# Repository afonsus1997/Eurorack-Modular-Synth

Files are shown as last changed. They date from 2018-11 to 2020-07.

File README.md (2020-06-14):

# Eurorack Modular Synth

## VCO

14 HP Digital voltage controlled oscillator.

### Main features

- Inputs
  - CV 1V/octave
  - FM in
  - Gate in
  - PWM in

* Output
  * Dual configurable audio outputs

#### Other features

Display LEDs for each audio input/output for visual feedback and for menu selection with the encoder.

## Power Supply

Using power supply design by [SyntherJack](https://syntherjack.net/)

* More information on the [project page](https://syntherjack.net/modular-synth-power-supply/)

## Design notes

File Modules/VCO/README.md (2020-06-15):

# VCO

Full DDS VCO module 

#### Dimensions

* 14HP (128.5x70.8mm)
  * PCB size (110x69mm)

### Main features

* Inputs
  * CV 1V/octave
  * FM in
  * Sync in
  * PWM in
* Output
  * Dual audio output with selectable waveforms

#### Main components

* Microcontroller
  * STM32F103RCT6 
* ADC
  * MCP3204
    * 12bit
    * 100ksps/4 channels
* DAC
  * DAC8551
    * 200ksps
    * 16bit
    * 1 channel
  * PCM1781DBQR
    * 192khz
    * 24bit
    * 2channel

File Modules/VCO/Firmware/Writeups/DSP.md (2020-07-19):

## Digital Representation

DAC output is 24bit -> 32bit variables are going to be used

int32: -4294967296 to +4294967295

## Ramp Integrator

-4294967296 to +4294967295

Ti/Ts = (2^32)/delta_i

fi = ((delta_i)/(2^32))*fs

delta_i = ((2^32)*fi)/fs

for addressing the wave table:

if wavetable only has half of the wave:

bit0 = sign

bit1:bit(number of wavetable samples+1) = wavetable addressing

bit(number of wavetable samples+2):bit31 = discarded

## CV Volt/Octave

The most popular choice seems to be that 0V is C2 (embraced by Doepfer and Kenton)

```
frequency = 440 / 2 ** 2.75 * 2 ** voltage
```

```
for pitch in range(61):
	voltage = pitch / 12
	frequency = 440 / 2 ** 2.75 * 2 ** voltage
	print(frequency)
```

http://bytenoise.co.uk/CV-gate

## Input sampling

input voltages 0 - 4.096

1st: 4096*0.001 (Q0 * Q15 = Q15) (Qm*Qk = Qm+k+1-n)

	-> 4096 * 32.768 = 134217.728

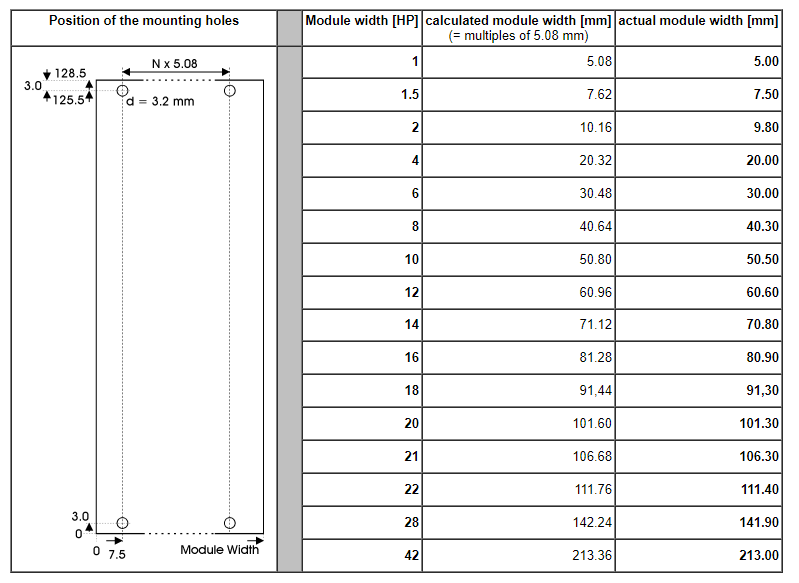
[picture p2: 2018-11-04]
Refs/Plate Sizes.png

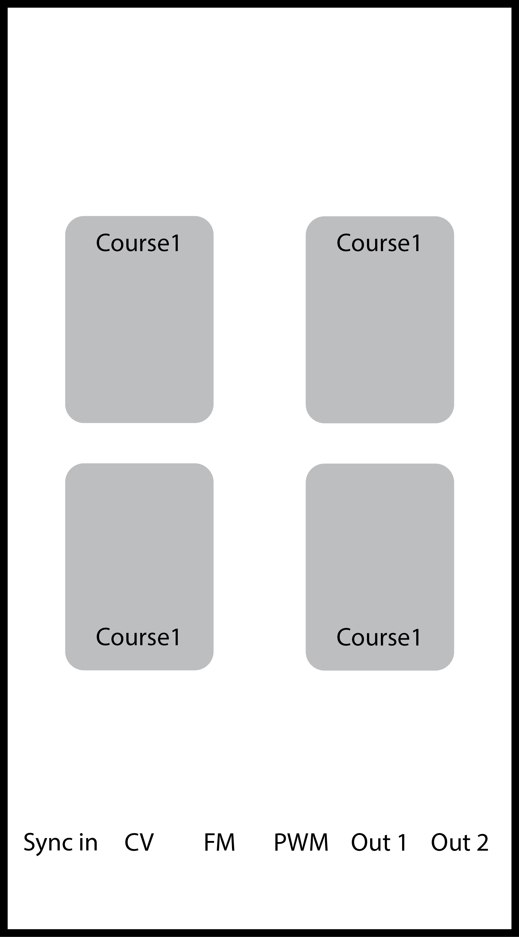
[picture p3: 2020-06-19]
Modules/VCO/Plate/VCO.png

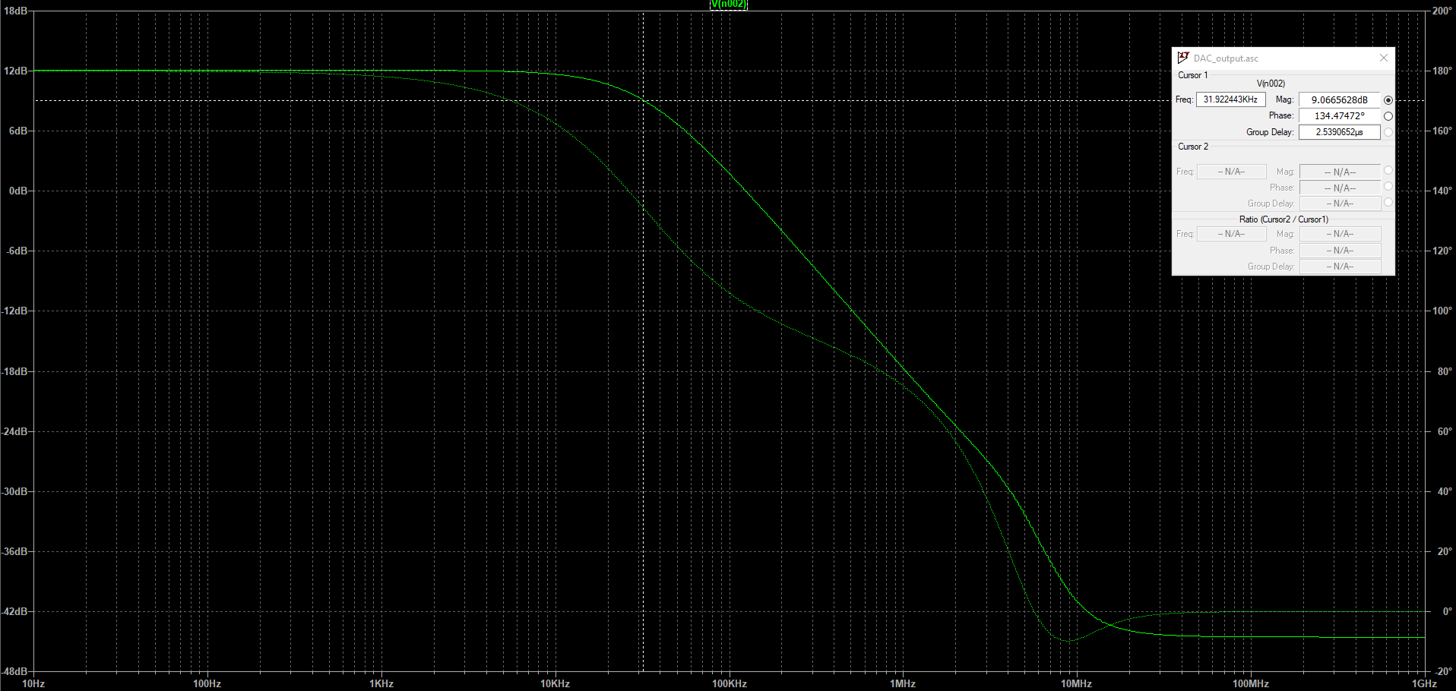
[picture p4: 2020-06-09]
Modules/VCO/Simulations/zero_impedance_output.png

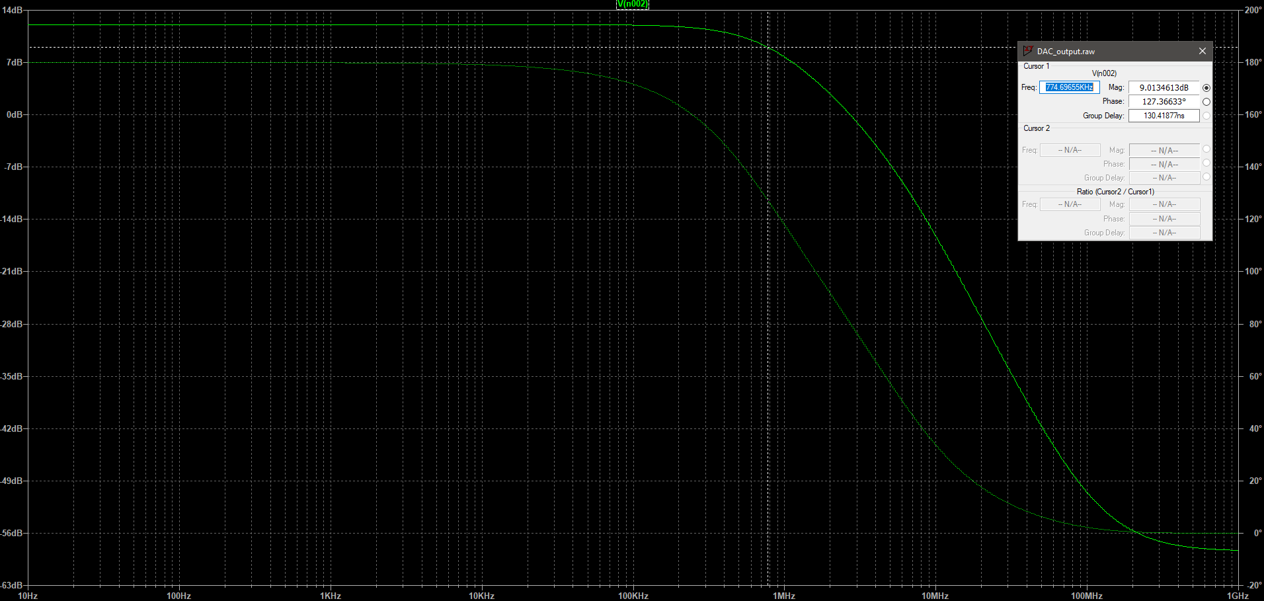
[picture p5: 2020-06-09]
Modules/VCO/Simulations/normal_feedback.png

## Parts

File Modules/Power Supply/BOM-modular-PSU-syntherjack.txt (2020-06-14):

Partlist for Euro Modular Synthesizer PSU

Qty Value     		        Parts                                                                                                             

Capacitors
                                                                                                          
4   1000u/25V       		C1, C2, C3, C4 
2   100n       				C5, C6 
2   10u/25V      			C7, C8 
2   1u/25V (tantalium)   	C9, C10                                                                                                           
                                                                                                              
Resistors 

4   2K 1%            		R1, R3, R8, R9     
2   240R 1%       			R2, R4                                                                                                           
2   100R          			R5, R6
1   14D391          		R7    

Semiconductors

2   1N4007          		D1, D2                                                                                                   
1   KBL06           		B1                                                                                                                
1   LM317T          		IC1                                                                                                               
1   LM337T          		IC2  
2   3mm LED        			LED1, LED2 

Other

13  6,3mm connector  +V-OUT1, +V-OUT2, +V-OUT3, -V-OUT1, -V-OUT2, -V-OUT3, AC-IN1, AC-IN2, AC-IN3, AC-IN4, GND-OUT1, GND-OUT2, GND-OUT3
2	Heatsink 6400B-P3 AAVID THERMALLOY (or similar that fits)
1	Toroidal transformer 60VA, 2x14V
1	100x160mm one-sided PCB

Notes:

Use C1/C2/C3/C4 1000u/25V or C1/C3 2200u/25V.

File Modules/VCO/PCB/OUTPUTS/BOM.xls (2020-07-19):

Designator | Value | Stock | Comment | Description | Quantity | Footprint | LibRef
RM14 | SHORT |  | Res1 | Resistor | 1 | RES0603R | Res1
RM13 | OPEN |  | Res1 | Resistor | 1 | RES0603R | Res1
CM1 | 100u |  | 100u |  | 1 | C 0603 / 1608 | Capacitor
CP1, CP2 | 100pF |  | Cap Pol2 | Polarized Capacitor (Axial) | 2 | C-RAD-4.5 | Cap Pol2
CP4, CP6 | 100n |  | Cap | Capacitor | 2 | C 0603 / 1608 | Cap
RD12, RD22, RD32, RD42, RD52, RD62, RIS11, RIS21, RIS31, RIS36, RIS41, ROS16, ROS26 | 100k |  | Res1, [NoValue] | Resistor | 13 | RES0603R | Res1
RD13, RD23, RD33, RD43, RD53, RD63 | 49.9k |  | Res1 | Resistor | 6 | RES0603R | Res1
COS14, COS24 | 47p |  | 47p |  | 2 | C 0603 / 1608 | Capacitor
RIS12, RIS22, RIS32 | 41.2k |  | Res1 | Resistor | 3 | RES0603R | Res1
ROS14, ROS24 | 30k |  |  | Resistor | 2 | RES0603R | Res1
RIS13, RIS14, RIS23, RIS24, RIS33, RIS34 | 24.9k |  | Res1 | Resistor | 6 | RES0603R | Res1
CP3, CP5 | 22u |  | Cap Pol2 | Polarized Capacitor (Axial) | 2 | C 0603 / 1608 | Cap Pol2
RIS35, ROS15, ROS25 | 20k |  |  | Potentiometer | 3 | SMD_POT_3x3mm | RPot
RM3, RM4, RM5, RM6 | 20k |  |  | Potentiometer | 4 | POT-rv09 | RPot
CM2, CM3 | 18p |  | 18pF |  | 2 | C 0603 / 1608 | Capacitor
CDAC3, CDAC5 | 10uF |  | Cap Pol1 | Polarized Capacitor (Radial) | 2 | C-RAD-4.5 | Cap Pol1
CADC2 | 10u |  | 10u |  | 1 | C 0603 / 1608 | Capacitor
COS13, COS23 | 10u |  | Cap Pol1 | Polarized Capacitor (Radial) | 2 | C-RAD-4.5 | Cap Pol1
CM5 | 10n |  | 10n |  | 1 | C 0603 / 1608 | Capacitor
LP1, LP2 | 10mH |  | Ferrite | Ferrite, Inductor | 2 | RES0805R | Inductor
RD11, RD21, RD31, RD41, RD51, RD61 | 10k |  | Res1 | Resistor | 6 | RES0603R | Res1
ROS11, ROS13, ROS21, ROS23 | 5.6k |  |  | Resistor | 4 | RES0603R | Res1
CDAC1, CDAC2 | 4.7-10uF |  | Cap Pol1 | Polarized Capacitor (Radial) | 2 | C-RAD-4.5 | Cap Pol1
COS11, COS21 | 3.9n |  | 3.9n |  | 2 | C 0603 / 1608 | Capacitor
ROS12, ROS22 | 3k |  |  | Resistor | 2 | RES0603R | Res1
RIS43 | 2k |  | Res1 | Resistor | 1 | RES0603R | Res1
CADC1, CADC4, CM4 | 1u |  | 1u |  | 3 | C 0603 / 1608 | Capacitor
CIS11, CIS21, CIS31, COS12, COS22 | 1n |  | Cap, 1n | Capacitor, [NoValue] | 5 | C 0603 / 1608 | Cap, Capacitor
RIS42, RM1, RM2, RM7, RM8, RM9, RM10, RM11, RM12, ROS17, ROS27 | 1k |  | Res1, [NoValue] | Resistor | 11 | RES0603R | Res1
CADC3, CD11, CD21, CD31, CD41, CD51, CD61, CDAC4, CIS32, CIS33, CIS34, CIS35, COS15, COS16, COS25, COS26 | 0.1u |  | 0.1u, Cap | [NoValue], Capacitor | 16 | C 0603 / 1608 | Capacitor, Cap
NT1, NT2 | 0 |  | Net_Tie | Resistor | 2 | RES0603R | Res1
RDAC1:4 |  |  | 742C083121JP | Res Thick Film Array 120 Ohm 5% 1/4W Â±200ppm/Â°C ISOL Molded 8-Pin 1206_4 X 0603_ Concave SMD Paper T/R | 1 | RESARRAY(4x0603) | Resistor Array 4x
UADC1 |  |  | MCP3204-CI/SL | 12 Bit Analog to Digital Converter 2, 4 Input 1 SAR 14-SOIC | 1 | SOIC-14 | MCP3204-CI/SL
UDAC1 |  |  | PCM1781DBQR | Converters - Digital to Analog _DAC_ 24-Bit, 192kHz, Ster Delta-Sig Audio DAC | 1 | SOP16-63P600X175-16N | PCM1781DBQR
UM1 |  |  | STM32F103RCT6 | ARMÂ® CortexÂ®-M3 STM32F1 Microcontroller IC 32-Bit 72MHz 256KB _256K x 8_ FLASH | 1 | QFP64P1200X1200X160-64N | STM32F103RCT6
XM1 |  |  | TSX-3225 | 16MHz Â±10ppm Crystal 9pF 60 Ohms 4-SMD, No Lead | 1 | TSX-3225 | TSX-3225
DM1, DM2, DM3, DM4, DM5, DM6 |  |  | LED0 | Typical INFRARED GaAs LED | 6 | LED2-2.54-D5.0MM | LED0
DP1, DP2 |  |  | 1N5819 |  | 2 | DO-41 | Diode
J02, JI1, JI2, JI3, JI4, JO1 |  |  | PJ-301 | https://www.snapeda.com/parts/PJ-301BM/Tayda%20Electronics/datasheet/ https://pt.aliexpress.com/item/32841677168.html?spm=a2g03.12057483.0.0.6dda4aeaXiyjRe https://lh3.googleusercontent.com/proxy/ZbPfZslDxdj8iWSgzh0kYZVEID9Zfc6SS9ZRHYvUB6heg4eTAyEEOQEiXlT2FamGh3ujXXQ57fTjbGyEKtdVl3hemL66LOj7ZA | 6 | PJ-301 | PJ-301
PM1, PP1 |  |  | Header 5X2 | Header, 5-Pin, Dual row | 2 | HDR2X5 | Header 5X2
PM2 |  |  | Header 4 | Header, 4-Pin | 1 | HDR1X4 | Header 4
SJM1, SJM2 |  |  | 2-Way Solder Jumper |  | 2 | SOLDERJUMPER_2WAY_OPEN_NOPASTE | SOLDERJUMPER_2WAY0603
SM1 |  |  | Switch |  | 1 | PUSH_SMD_3x4 | B3U-1000P
SM2 |  |  | ENCODER |  | 1 | Rotary Encoder | ENCODER
UADC2 |  |  | 4.096 VREF | 4.096 Voltage reference | 1 | SOT-23-3 | MCP1541
UIS1, UIS2 |  |  | TL074 |  | 2 | SOIC-14 | TL074
UOS1, UOS2 |  |  | Dual NE5532 opamp |  | 2 | SOIC-8 | NE5532
UP1, UP2 |  |  | 3v3 REG, 5VREG | LDO 3.3V/5V/12V | 2 | SOT-223-3 - REG | AMS1117

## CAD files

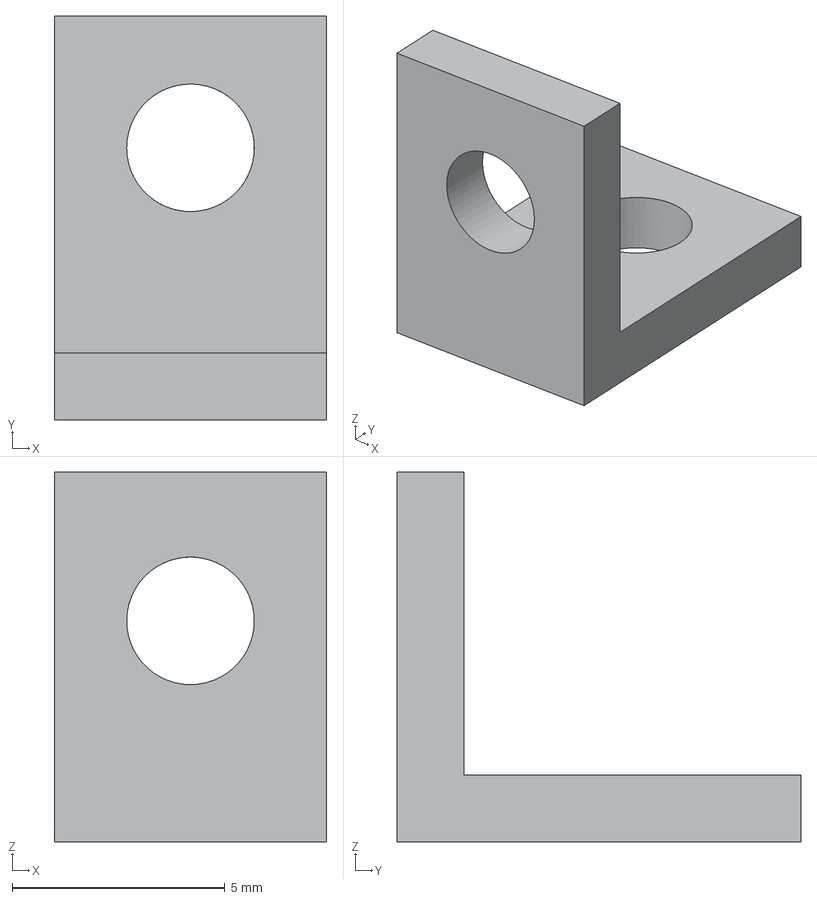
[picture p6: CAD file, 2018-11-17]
Modules/VCA/Altium 3D/L bracket.step
6.40 x 9.50 x 8.70 mm

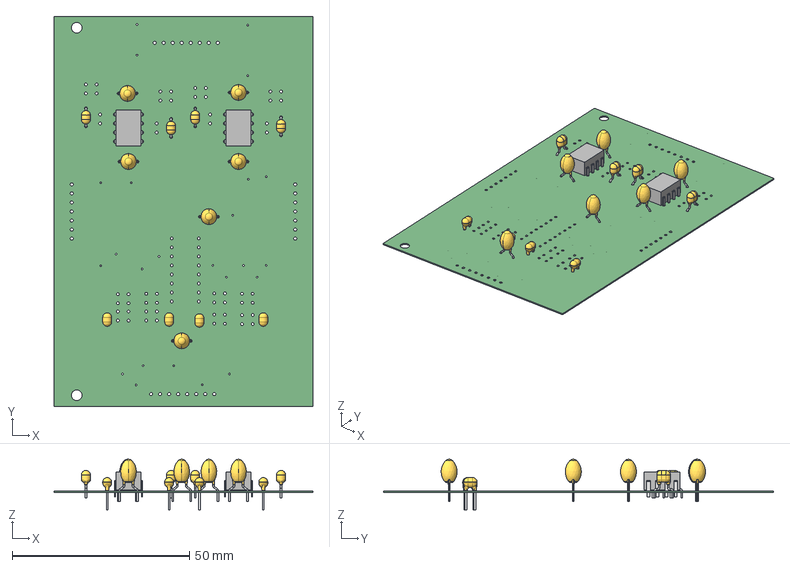
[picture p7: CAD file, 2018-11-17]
Modules/VCA/VCA_1/VCA_1.step
73.0 x 110.0 x 14.3 mm
Board
Extruded x 50
CAPPRB508-450X850 x 6
CAPRR254-254X381X381 x 4
CAPRR508-254X381X584 x 4

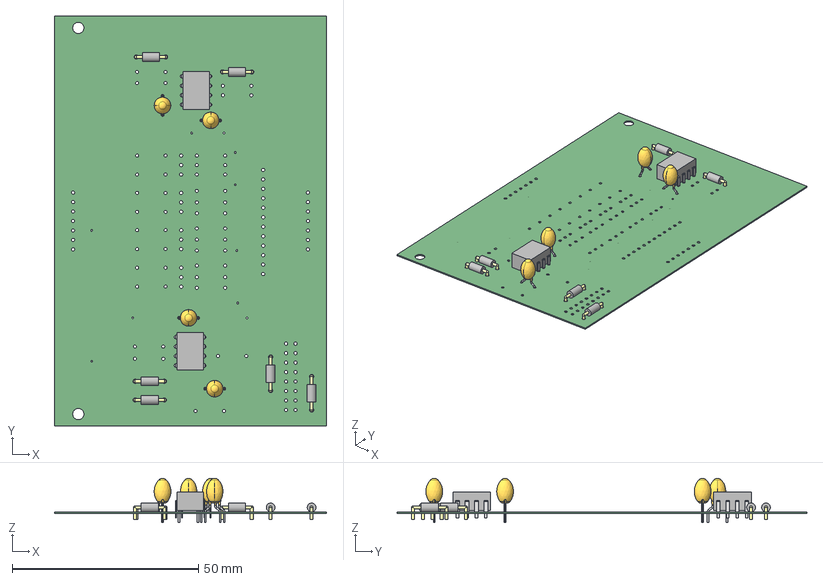
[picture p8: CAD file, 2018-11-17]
Modules/VCA/VCA_2/VCA_2.step
73.0 x 110.0 x 11.9 mm
Board
Extruded x 50
CAPPRB508-450X850 x 4

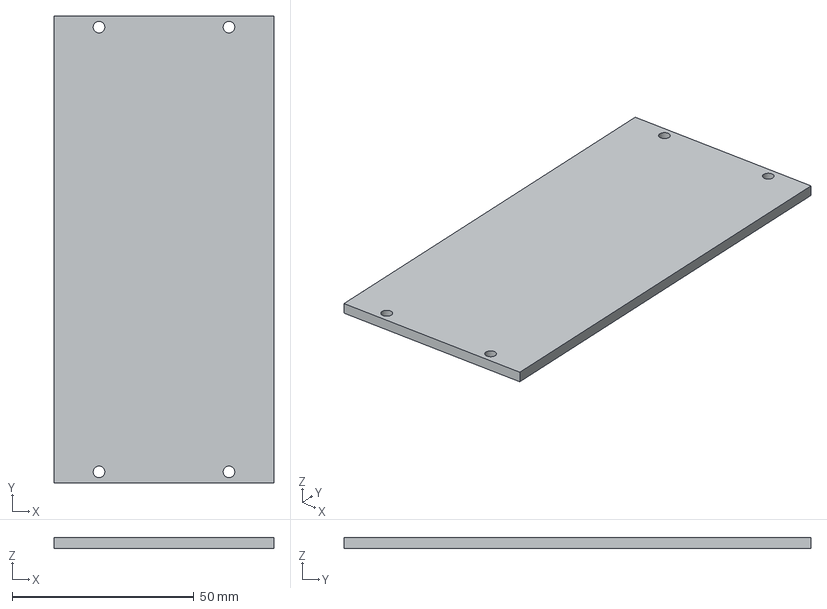
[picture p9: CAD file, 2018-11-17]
Modules/VCA/Altium 3D/VCA_face_plate.step
60.6 x 128.5 x 3.00 mm

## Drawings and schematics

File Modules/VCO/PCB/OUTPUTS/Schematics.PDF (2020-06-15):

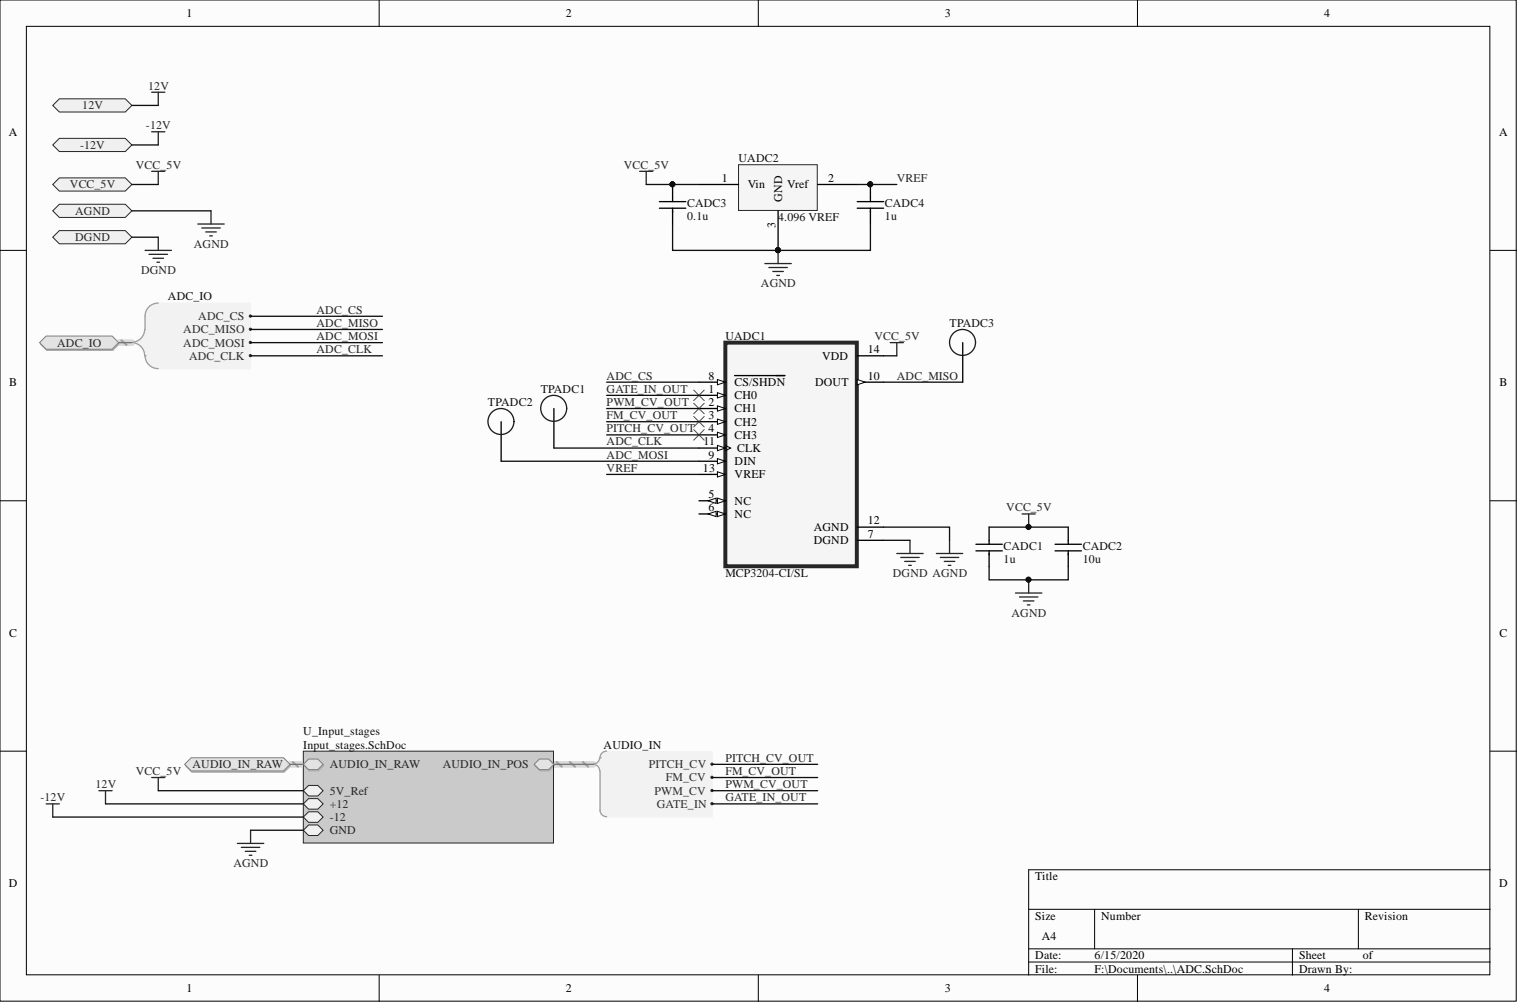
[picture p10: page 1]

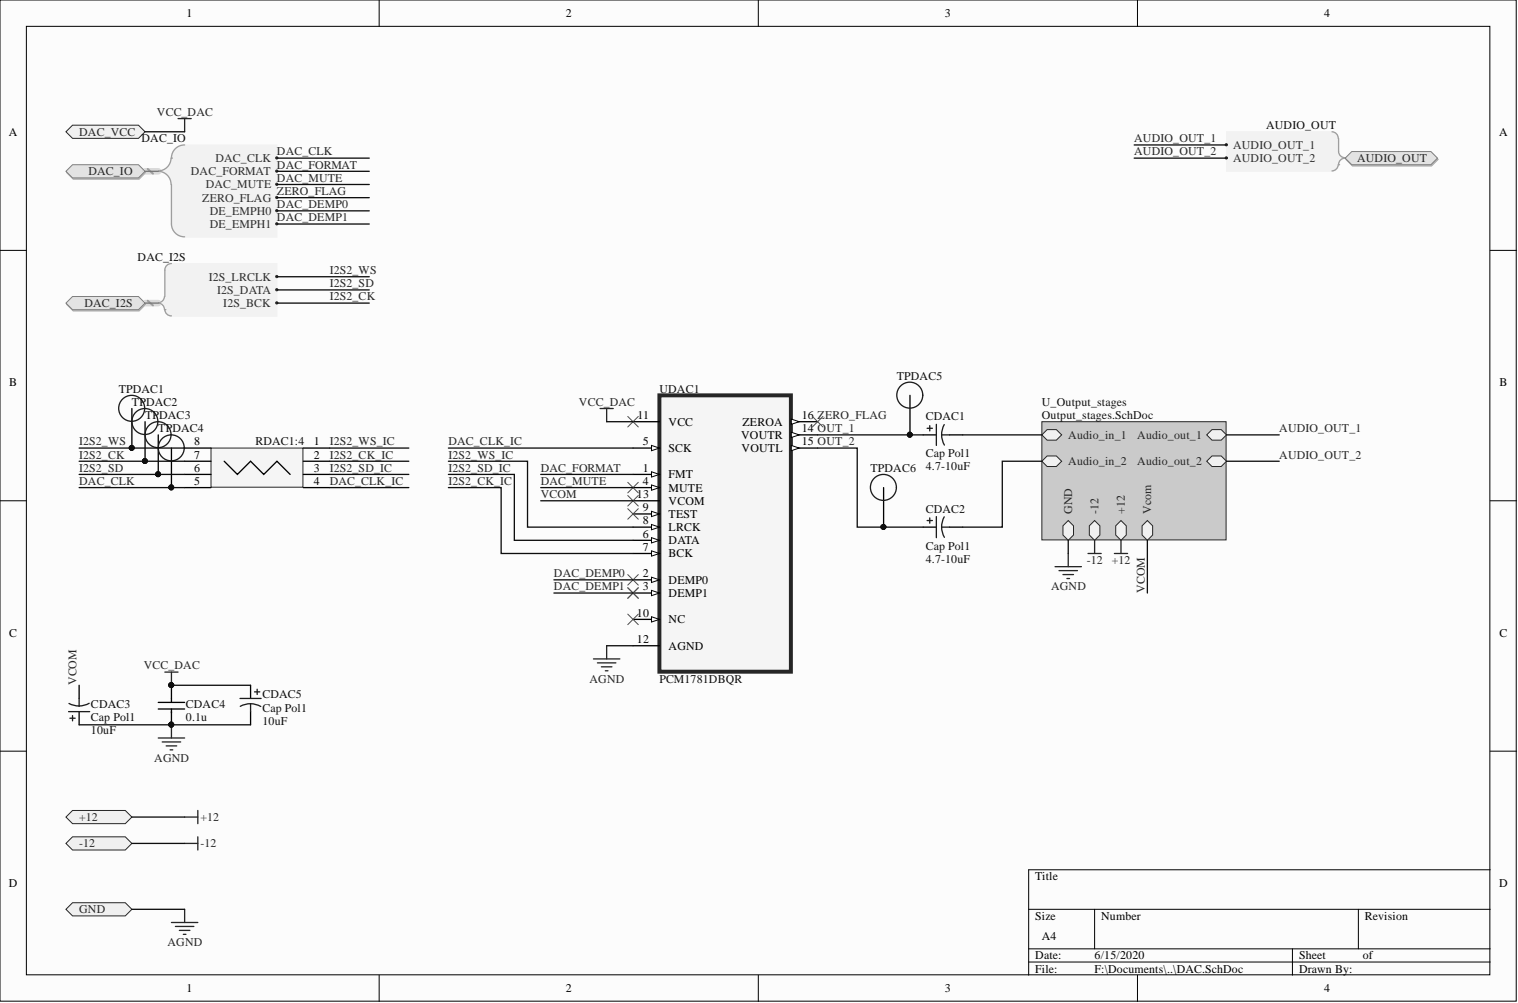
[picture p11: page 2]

MUTE 4

VCOM | VCOM 13 TEST 9

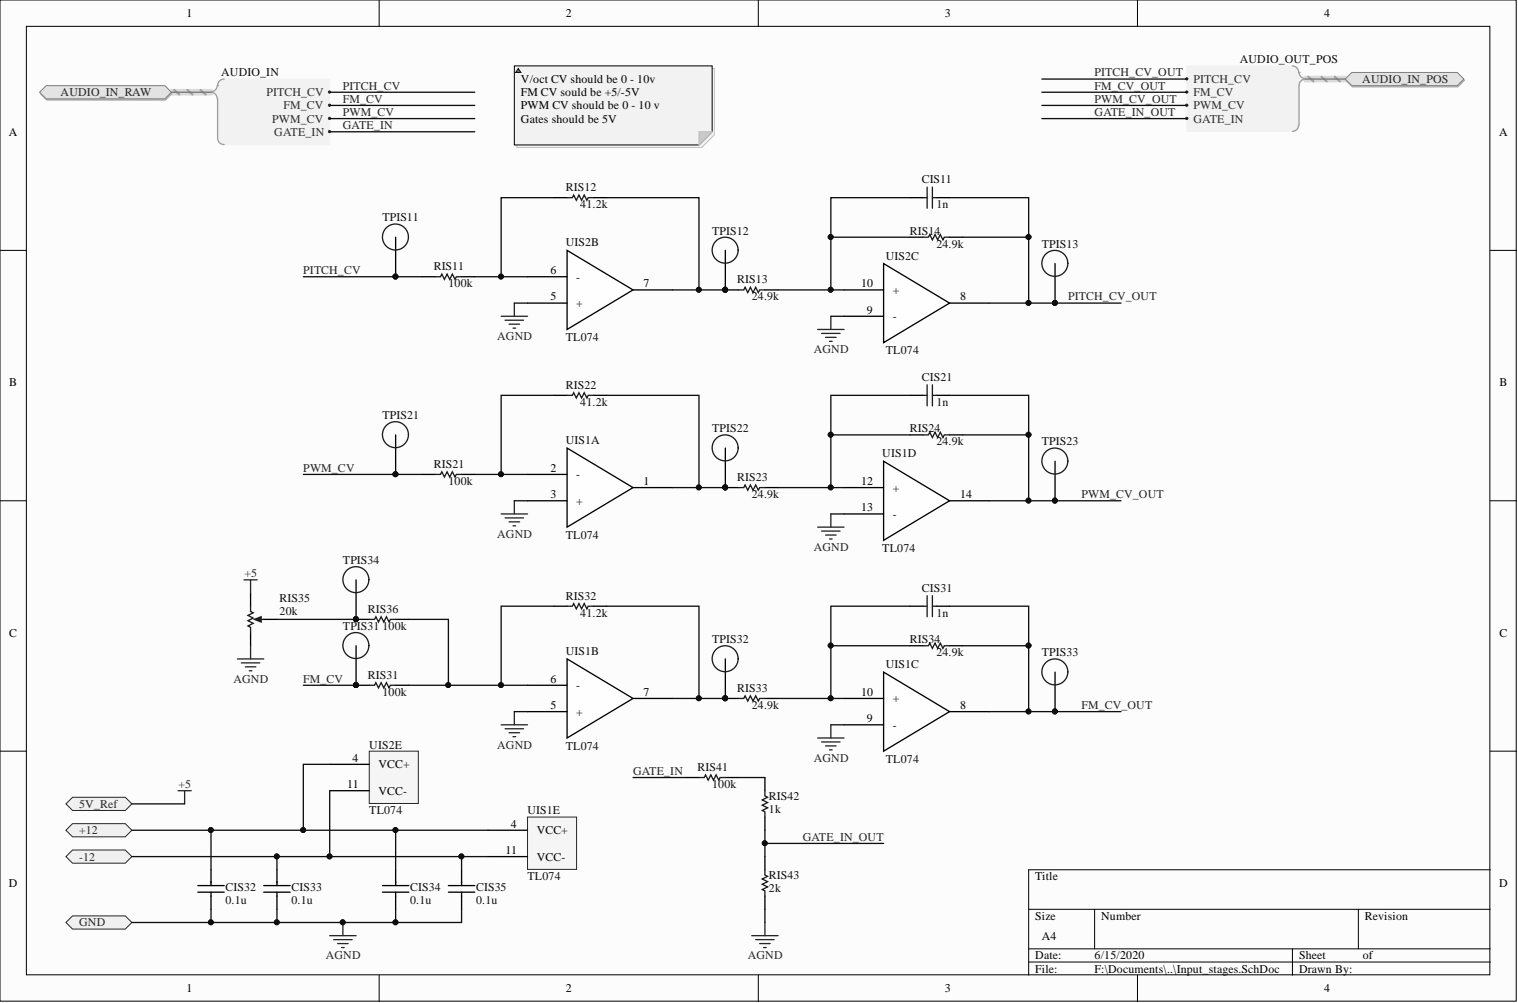
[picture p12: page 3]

V/oct CV should be 0 - 10v
FM CV sould be +5/-5V
PWM CV should be 0 - 10 v
Gates should be 5V

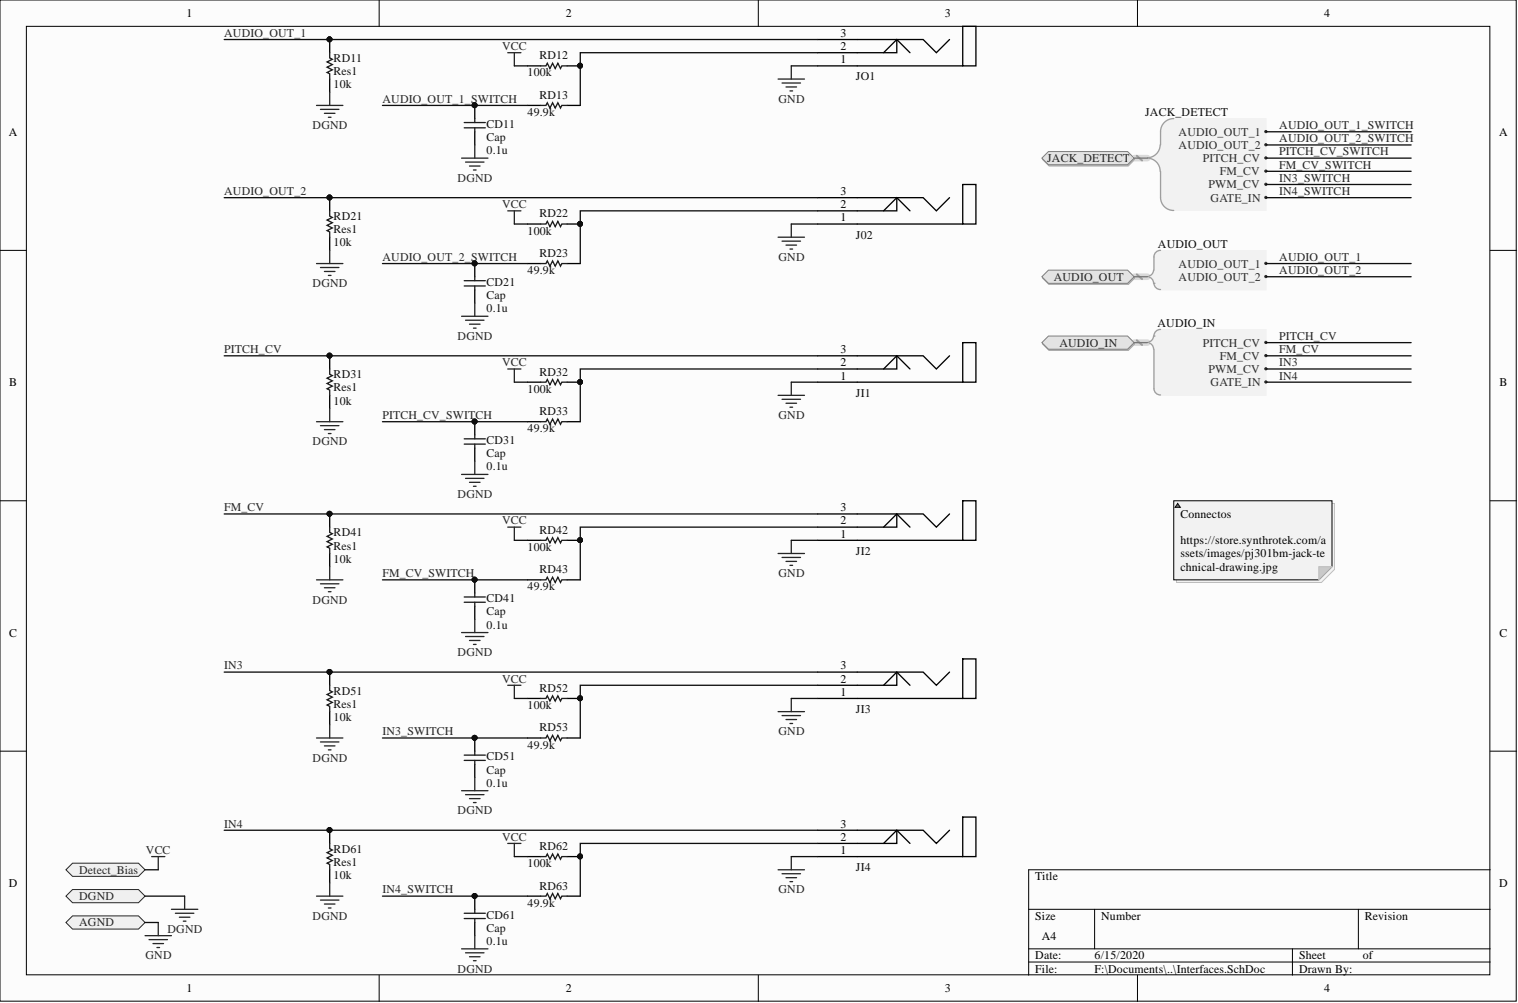
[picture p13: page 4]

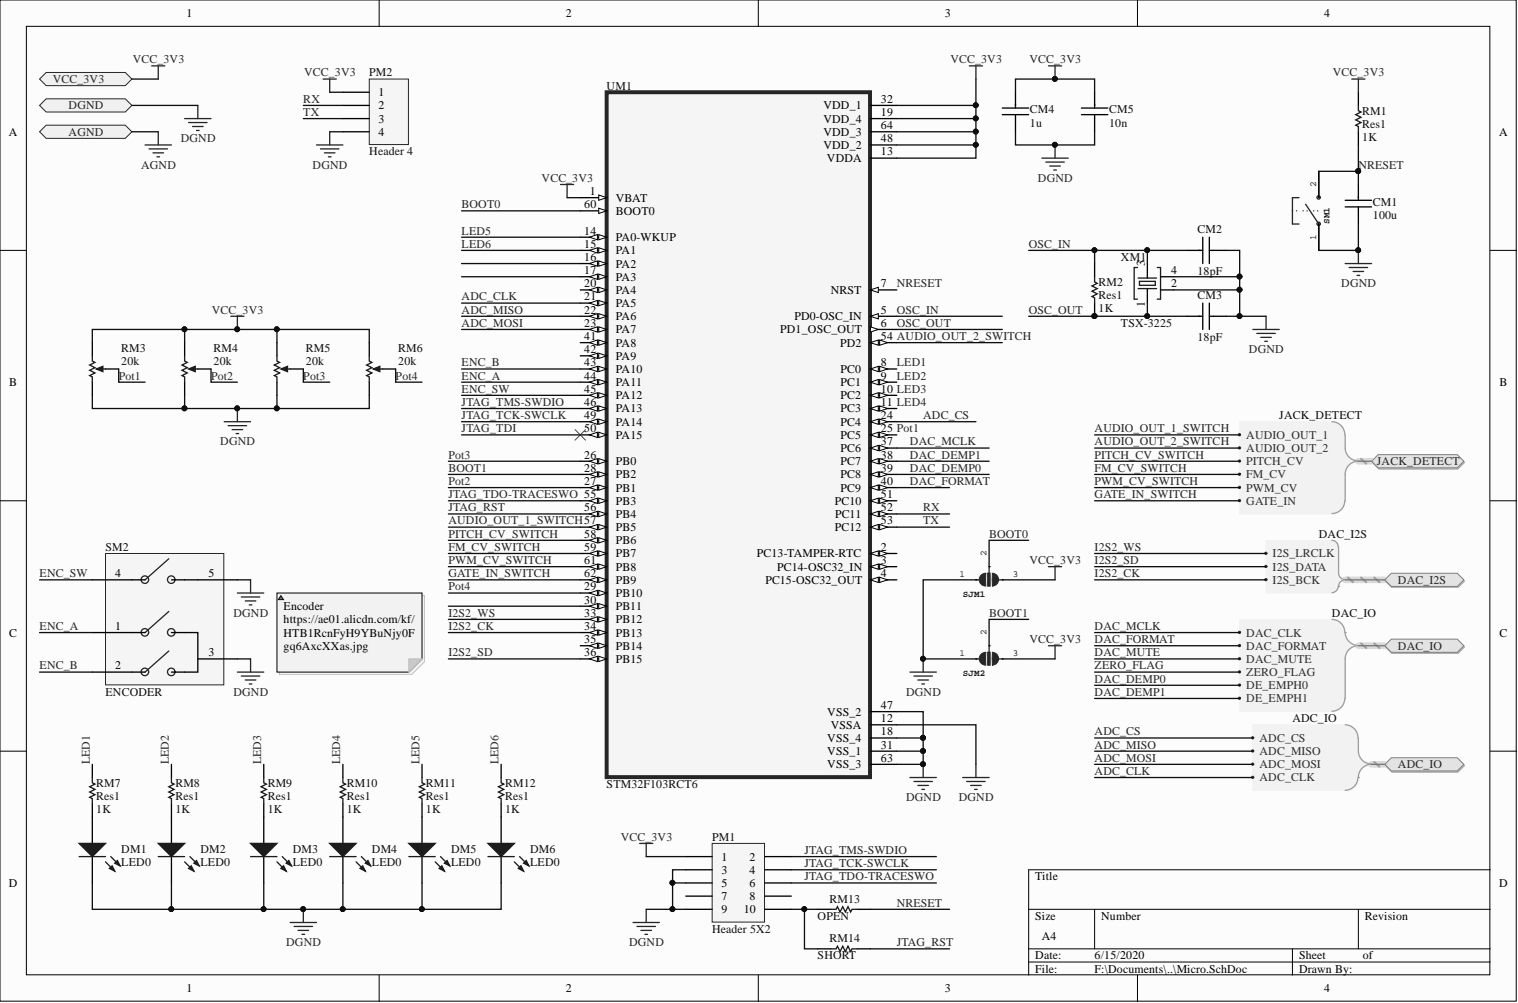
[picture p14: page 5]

1 2
1 8
3 1
6 3

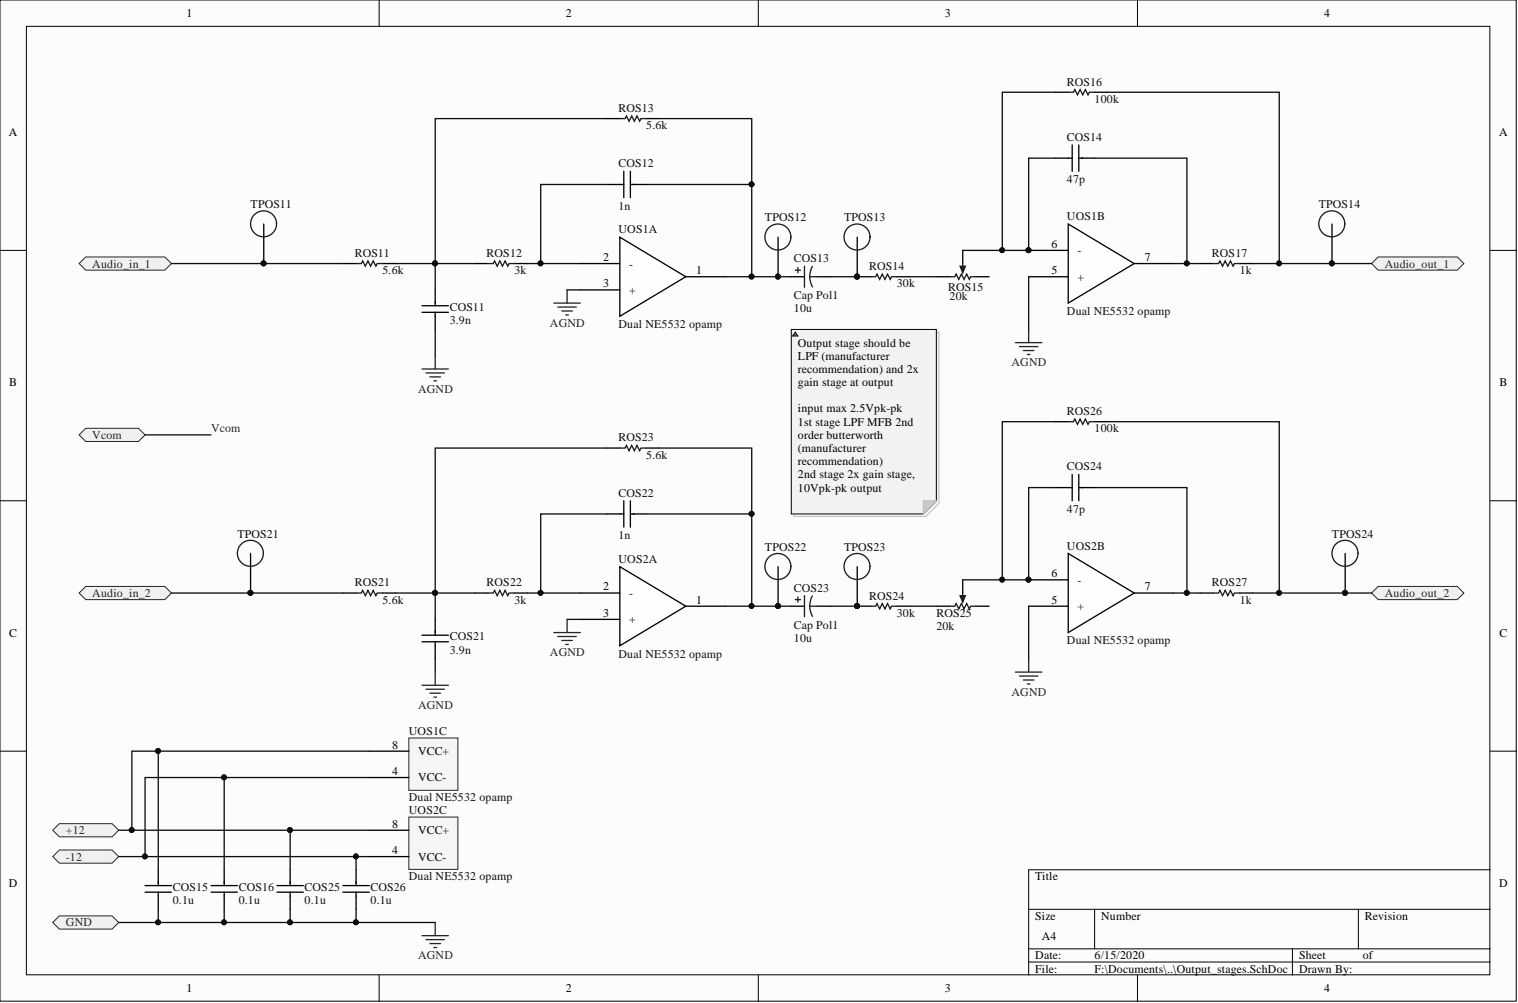
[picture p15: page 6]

Output stage should be
LPF (manufacturer
recommendation) and 2x
gain stage at output

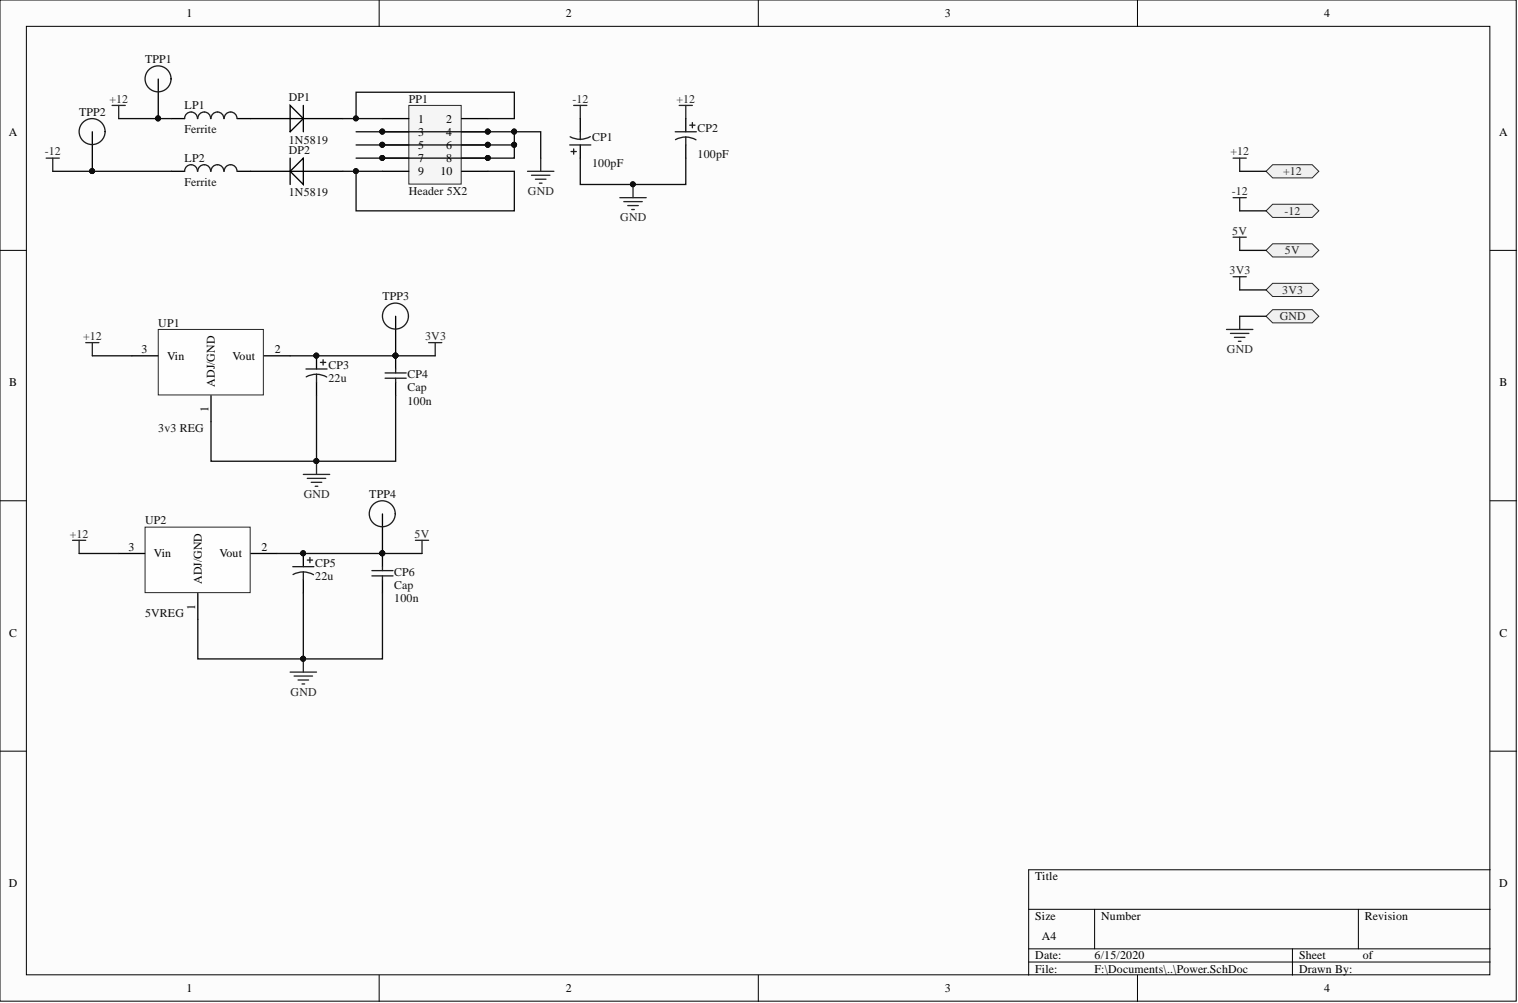
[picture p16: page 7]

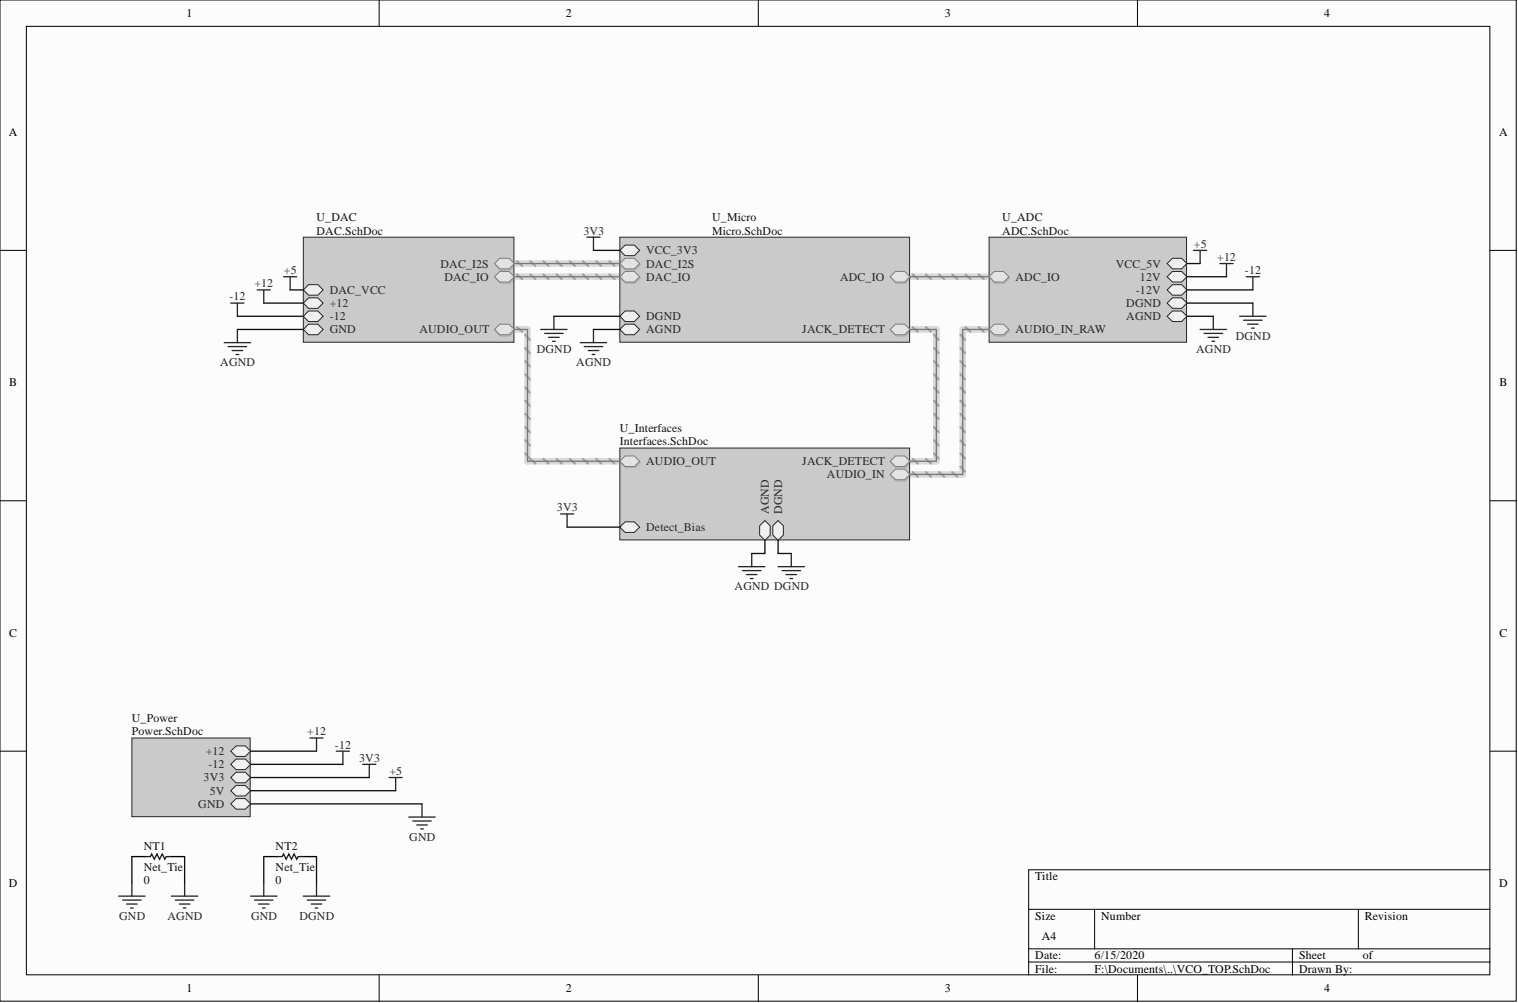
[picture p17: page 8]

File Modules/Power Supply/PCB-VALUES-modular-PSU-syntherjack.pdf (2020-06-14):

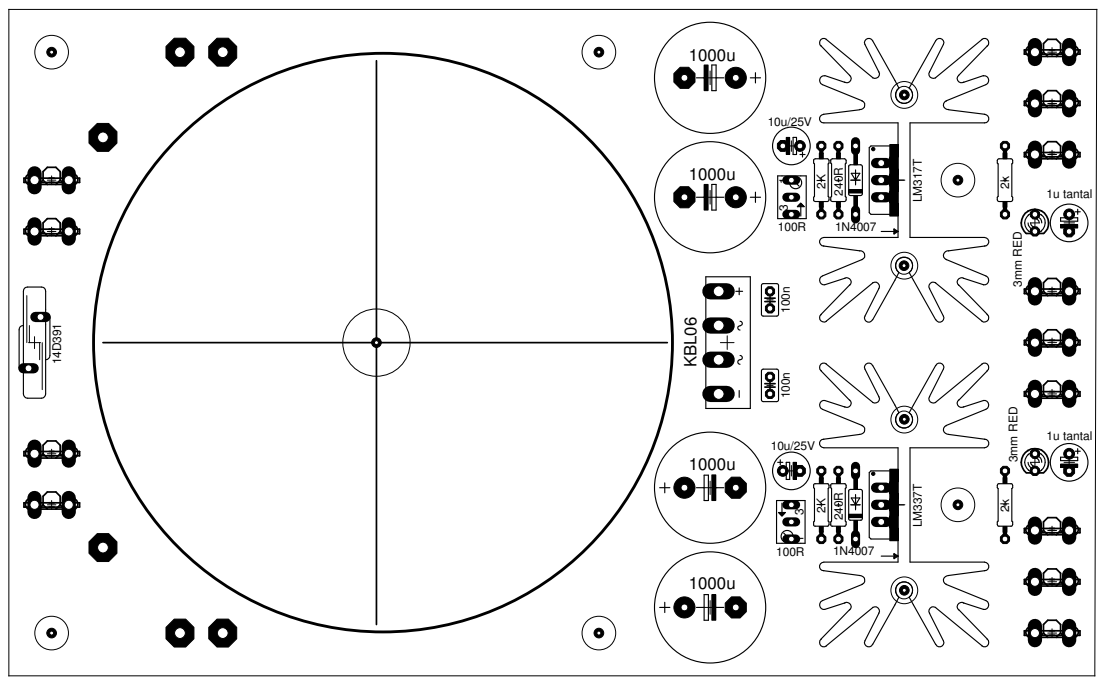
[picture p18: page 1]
KBL06; 1u tantal; 3mm RED 3mm RED 2k 2k

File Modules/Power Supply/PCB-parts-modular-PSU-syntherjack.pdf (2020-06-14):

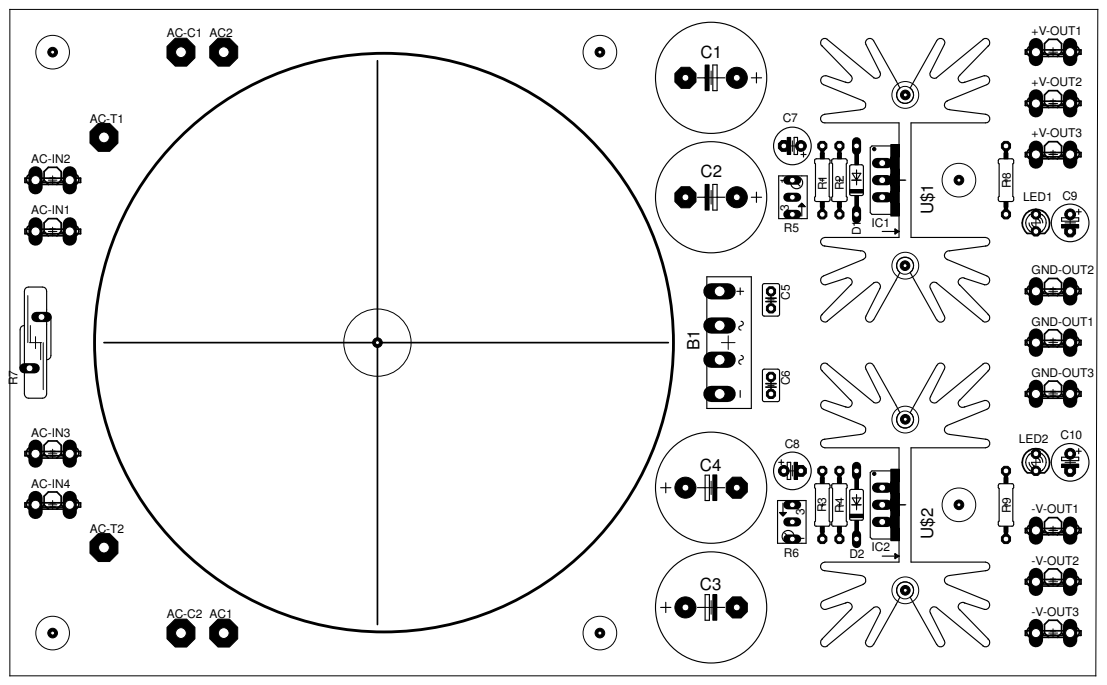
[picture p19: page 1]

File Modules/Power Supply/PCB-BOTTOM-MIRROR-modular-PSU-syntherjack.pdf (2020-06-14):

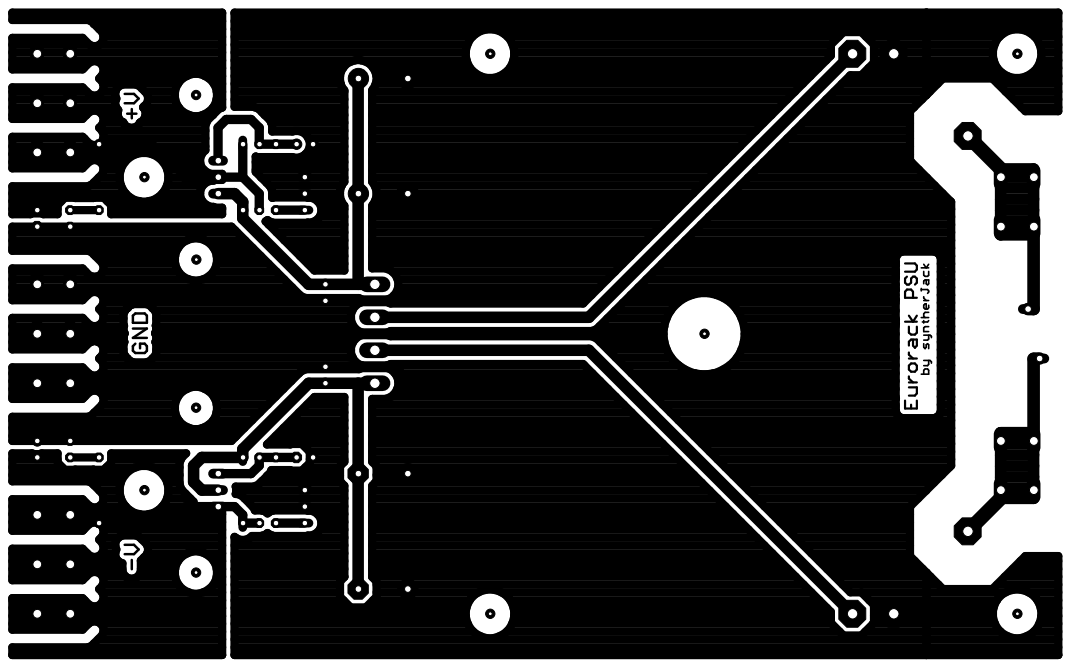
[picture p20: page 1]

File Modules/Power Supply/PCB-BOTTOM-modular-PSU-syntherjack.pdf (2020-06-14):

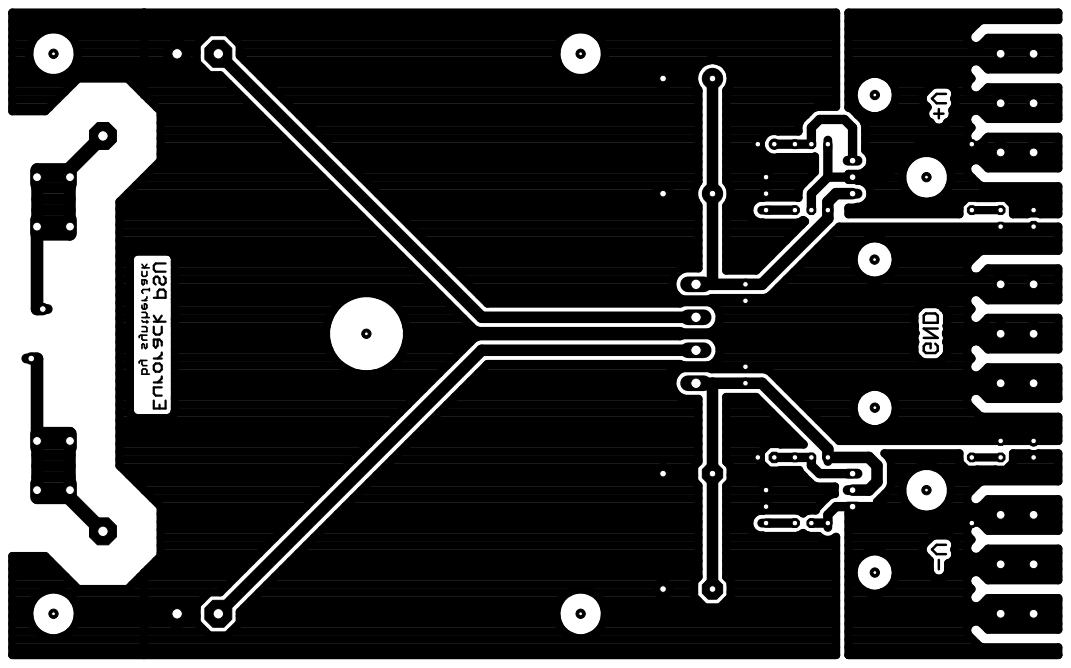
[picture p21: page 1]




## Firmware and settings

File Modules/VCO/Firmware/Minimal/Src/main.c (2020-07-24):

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

/* Includes ------------------------------------------------------------------*/
#include "main.h"

/* USER CODE BEGIN Includes */
#include "mcp3204.h"
#include "DSPmain.h"
#include "stm32_HAL.h"
#include "interfaces.h"
// extern uint32_t potVals[4];
/* USER CODE END Includes */

/* USER CODE BEGIN PTD */
uint16_t pot1, pot2, pot3, pot4;
uint16_t adcbuf[4];
// extern uint8_t jackStatus[6];
/* USER CODE END PTD */

ADC_HandleTypeDef hadc1;
DMA_HandleTypeDef hdma_adc1;

I2S_HandleTypeDef hi2s2;
DMA_HandleTypeDef hdma_spi2_tx;

SPI_HandleTypeDef hspi1;

TIM_HandleTypeDef htim6;

UART_HandleTypeDef huart4;

/* USER CODE BEGIN PV */
HAL_ADC_ConvCpltCallback(ADC_HandleTypeDef* hadc){
  for (int i = 0; i < 4; i++)
  {
    potVals[i] = adcbuf[i];
  }
  
}
/* USER CODE END PV */

void SystemClock_Config(void);
static void MX_GPIO_Init(void);
static void MX_DMA_Init(void);
static void MX_ADC1_Init(void);
static void MX_I2S2_Init(void);
static void MX_SPI1_Init(void);
static void MX_UART4_Init(void);
static void MX_TIM6_Init(void);
/**
  * @brief  The application entry point.
  * @retval int
  */
int main(void)
{
  /* USER CODE BEGIN 1 */
  // adcRead(1);
  /* USER CODE END 1 */
  

  /* MCU Configuration--------------------------------------------------------*/

  /* Reset of all peripherals, Initializes the Flash interface and the Systick. */
  HAL_Init();

  /* Configure the system clock */
  SystemClock_Config();

  /* Initialize all configured peripherals */
  MX_GPIO_Init();
  MX_DMA_Init();
  MX_ADC1_Init();
  MX_I2S2_Init();
  MX_SPI1_Init();
  MX_UART4_Init();
  MX_TIM6_Init();
  /* USER CODE BEGIN 2 */
  HAL_TIM_Base_Start_IT(&htim6);
  // HAL_ADCEx_Calibration_Start(&hadc1);
  HAL_ADC_Start_DMA(&hadc1, adcbuf, 4);
  // HAL_ADC_PollForConversion(&hadc1, HAL_MAX_DELAY);
  uint16_t raw;
  /* USER CODE END 2 */

  /* Infinite loop */
  /* USER CODE BEGIN WHILE */
  while (1)
  {
    /* USER CODE END WHILE */

    /* USER CODE BEGIN 3 */
    // pot1 = potVals[Pot1];
    // pot2 = potVals[Pot2];
    // pot3 = potVals[Pot3];
    // pot4 = potVals[Pot4];

    updateJackStatus();
    

  }
  /* USER CODE END 3 */
}

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


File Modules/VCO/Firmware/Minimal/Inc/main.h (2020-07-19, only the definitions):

#define LED1_Pin GPIO_PIN_0
#define LED1_GPIO_Port GPIOC
#define LED2_Pin GPIO_PIN_1
#define LED2_GPIO_Port GPIOC
#define LED3_Pin GPIO_PIN_2
#define LED3_GPIO_Port GPIOC
#define LED4_Pin GPIO_PIN_3
#define LED4_GPIO_Port GPIOC
#define LED5_Pin GPIO_PIN_0
#define LED5_GPIO_Port GPIOA
#define LED6_Pin GPIO_PIN_1
#define LED6_GPIO_Port GPIOA
#define POT4_Pin GPIO_PIN_4
#define POT4_GPIO_Port GPIOA
#define GPIO_ADC_CS_Pin GPIO_PIN_4
#define GPIO_ADC_CS_GPIO_Port GPIOC
#define POT1_Pin GPIO_PIN_5
#define POT1_GPIO_Port GPIOC
#define POT3_Pin GPIO_PIN_0
#define POT3_GPIO_Port GPIOB
#define POT2_Pin GPIO_PIN_1
#define POT2_GPIO_Port GPIOB
#define DEMP1_Pin GPIO_PIN_7
#define DEMP1_GPIO_Port GPIOC
#define DEMP0_Pin GPIO_PIN_8
#define DEMP0_GPIO_Port GPIOC
#define DACFORMAT_Pin GPIO_PIN_9
#define DACFORMAT_GPIO_Port GPIOC
#define ENCB_Pin GPIO_PIN_10
#define ENCB_GPIO_Port GPIOA
#define ENCA_Pin GPIO_PIN_11
#define ENCA_GPIO_Port GPIOA
#define ENCSW_Pin GPIO_PIN_12
#define ENCSW_GPIO_Port GPIOA
#define AUDIO_OUT_2_SW_Pin GPIO_PIN_2
#define AUDIO_OUT_2_SW_GPIO_Port GPIOD
#define AUDIO_OUT_1_SW_Pin GPIO_PIN_5
#define AUDIO_OUT_1_SW_GPIO_Port GPIOB
#define PITCH_CV_SWITCH_Pin GPIO_PIN_6
#define PITCH_CV_SWITCH_GPIO_Port GPIOB
#define FM_CV_SWITCH_Pin GPIO_PIN_7
#define FM_CV_SWITCH_GPIO_Port GPIOB
#define PWM_SW_Pin GPIO_PIN_8
#define PWM_SW_GPIO_Port GPIOB
#define GATE_SW_Pin GPIO_PIN_9
#define GATE_SW_GPIO_Port GPIOB

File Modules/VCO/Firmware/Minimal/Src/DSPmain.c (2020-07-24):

#include "DSPmain.h"


int32_t RampIntegratorState0 = 0;
int32_t RampIntegratorState1 = 0;

uint8_t currentWave0 = 0;
uint8_t currentWave1 = 0;

int16_t sampleBuffer1[SAMPLEBUFFERSIZE];
int16_t sampleBuffer2[SAMPLEBUFFERSIZE];

uint16_t transferBuffer1[TRANSFERBUFFERSIZE];
uint16_t transferBuffer2[TRANSFERBUFFERSIZE];



// void HAL_TIM_PeriodElapsedCallback(TIM_HandleTypeDef *htim)
// {
//     // if (htim->Instance == TIM6) {
        
//     // }
// }

extern "C" void HAL_I2S_TxCpltCallback(I2S_HandleTypeDef *hi2s)
{
  // second half finished, filling it up again while first  half is playing
  for (uint8_t i = 0; i < 25; i++)
  {
      
  }
  
}
extern "C" void HAL_I2S_TxHalfCpltCallback(I2S_HandleTypeDef *hi2s)
{
  // first half finished, filling it up again while second half is playing
}

int32_t NCO0(uint8_t wave, uint16_t freq){
    uint32_t delta_i;


    delta_i = (pow(2,32)*freq)/SAMPLING_FREQ;

    RampIntegratorState0 = RampIntegratorState0 + delta_i;

    switch (wave)
    {
    case sine:
        return sineProcessor(RampIntegratorState0);
        break;
    
    default:
        break;
    }

}

uint32_t sineProcessor(int16_t integratorState){
    int32_t preSine;
    uint32_t sineOut;
    preSine = RampIntegratorState0 >> SINE_SHIFT;
    preSine &= SINE_SHIFT_MASK;

    preSine = SineWave[preSine];
    if(integratorState<0)
        preSine = -preSine;
    
    sineOut = preSine + INT32_OFFSET;
    sineOut >> 8; //conversion to dac 24bit

    return sineOut;
}

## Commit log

2018-11-02 added refs and started building the case
    [Case.cfg]
2018-11-04 did some research, modeled some stuff
    [Case.cfg]
2018-11-10 started designing vca
    [VCA.PrjPCB, VCA.SchDoc, ssm2164_2.PCBLIB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]
2018-11-10 almost done with the schm
    [VCA.PrjPCB, VCA.SchDoc]
2018-11-11 finished schematic, started working on the layout
    [VCA.PcbDoc, VCA.PrjPCB, VCA.SchDoc]
2018-11-11 more layout done
    [VCA.PcbDoc]
2018-11-11 layout almost done
    [VCA.PcbDoc, VCA.SchDoc]
2018-11-17 splitted vca into 2 boards
    [Case.cfg, VCA.PcbDoc, VCA.PrjPCB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]
2018-11-17 exported 3d models of pcb
    [L bracket.step, VCA.PcbDoc, VCA_1.step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]
2018-11-18 added vca module to 3d cad assembly
    [Case.cfg, VCA.cfg]
2020-05-12 Added load of vco stuff
    [Interfaces.SchDoc, L bracket.step, Micro.SchDoc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]
2020-06-09 Added vco stuff
    [DAC.SchDoc, Micro.SchDoc, VCO.PrjPcb]
2020-06-10 Simulations, pcb design
    [DAC.SchDoc, Input_stages.SchDoc, Interfaces.SchDoc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]
2020-06-10 VCO(Completed DAC, added interfaces, misc changes)
    [DAC.SchDoc, Interfaces.SchDoc, Micro.SchDoc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]
2020-06-10 VCO(Added power, misc changes)
    [Input_stages.SchDoc, Micro.SchDoc, Power.SchDoc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]
2020-06-12 VCO(added missing input changes, added bypass caps, added vref, and misc adds)
    [DAC.SchDoc, Input_stages.SchDoc, Interfaces.SchDoc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]
2020-06-12 added and fixed pot
    [Interfaces.SchDoc, Micro.SchDoc, Output_stages.SchDoc]
2020-06-12 VCO(added leds, added boot pins, assigned some pins)
    [ADC.SchDoc, Micro.SchDoc]
2020-06-13 VCO(misc schematic changes, layout)
    [ADC.SchDoc, DAC.SchDoc, Input_stages.SchDoc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]
2020-06-13 VCO(Layout almost done)
    [Interfaces.SchDoc, Micro.SchDoc, VCO.PcbDoc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]
2020-06-13 VCO(Rounting complete. DRC checked. Need silkscreen redo)
    [ADC.SchDoc, Input_stages.SchDoc, Micro.SchDoc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]
2020-06-14 VCO(added schematic)
2020-06-14 VCO(fixed diodes, added ferrite, did top silkscreen)
2020-06-14 VCO(did bottom silk)
    [Power.SchDoc, VCO.PrjPcb]
2020-06-14 VCO(minor changes)
    [Power.SchDoc, VCO.PrjPcb]
2020-06-14 Reorganization of files. Minor changes
    [ADC.SchDoc, DAC.SchDoc, Input_stages.SchDoc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]
2020-06-14 VCO(fixed values, added bom)
    [ADC.SchDoc, BOM.xls, DAC.SchDoc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]
2020-06-14 edited bom
    [BOM.xls]
2020-06-15 VCO(misc changes, added gerbers to output)
    [ADC.SchDoc, DAC.SchDoc, Input_stages.SchDoc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]
2020-06-15 VCO(added logos, final touched on the board, sent to fab)
    [VCO.GBL, VCO.GBO, VCO.GBP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]
2020-06-19 VCO(added content, fixed pin on layout, updated pins on cube)
    [Micro.SchDoc]
2020-07-19 VCO(firmware updates)
    [BOM.xls, PitchCV.xlsx]
2020-07-24 VCO(firmware changes and updates)
    [stm32f1x.cfg]

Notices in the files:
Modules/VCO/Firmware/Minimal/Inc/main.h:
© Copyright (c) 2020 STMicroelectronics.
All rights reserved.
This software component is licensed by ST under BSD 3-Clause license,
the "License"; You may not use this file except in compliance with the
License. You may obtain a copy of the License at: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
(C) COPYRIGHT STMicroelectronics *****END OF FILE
